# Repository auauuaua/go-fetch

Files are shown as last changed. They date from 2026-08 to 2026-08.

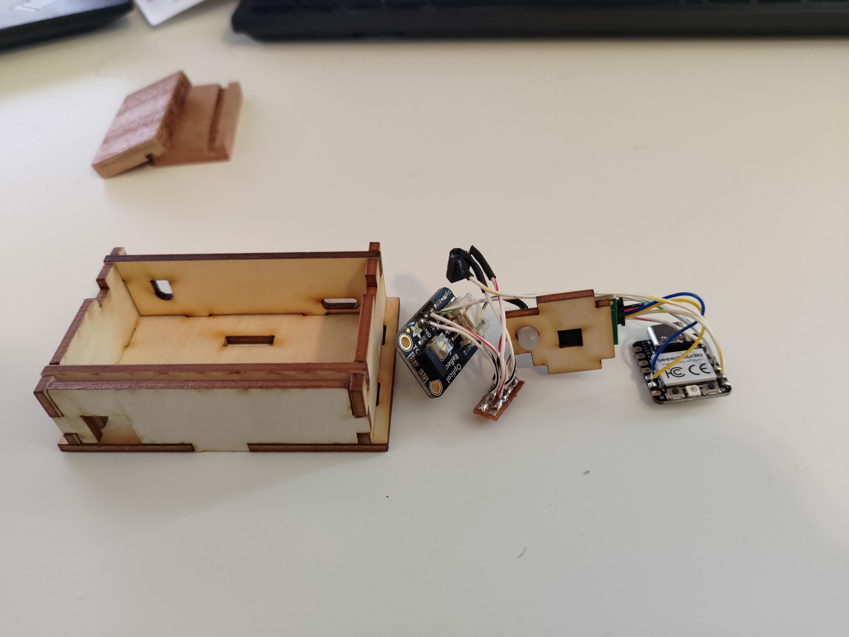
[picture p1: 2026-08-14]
go fetch Card Player Hardware/Images/P_20260420_094052_clean.jpg

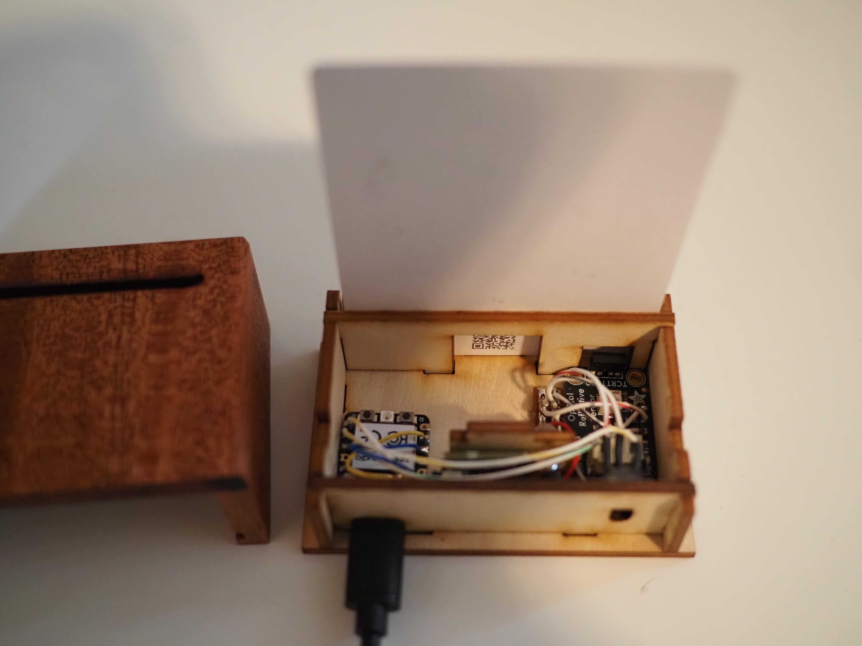
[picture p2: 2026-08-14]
go fetch Card Player Hardware/Images/P4224178_clean.JPG

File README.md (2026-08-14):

# go fetch
## De-digital horror-ify your life: hands on  physical method for accessing digital media
...and software to make viewing it suck less

## A system for easily pulling up your favorite photo albums, music playlists, etc, without touching a computer or phone.

The hardware and companion Windows software allows you to link a QR code to any file/website/etc.

The hardware accepts a standard poker sized card with the QR code on the back, so it feels more like putting in a CD than scanning a code.

The software allows easy setup of the card layout so you can get them printed, or print on cardstock yourself.

It's customizable to launch any file or link from any QR code with any program, and allows you send program specific commands to the program through a IR remote.

1. go fetch Card Player - Windows PC Editor and Launcher

2. go fetch Card Player Arduino - Arduino code for the hardware

3. go fetch Card Player Hardware - CAD Files, Schematics, etc.

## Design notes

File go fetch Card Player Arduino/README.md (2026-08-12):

# Go Fetch Card Player - Arduino

Firmware for the Go Fetch Card Player, running on a Seeed Studio XIAO RP2040. Reads QR codes from physical cards via a Tiny Code Reader (I2C) and receives IR remote signals, reporting both over Serial.

---

## Hardware

| Component | Details |
|---|---|
| Microcontroller | Seeed Studio XIAO RP2040 |
| QR Scanner | Tiny Code Reader (Useful Sensors) — I2C |
| IR Receiver | Connected to pin D2 |
| Card Detect Switch | Connected to pin D4 (active LOW, INPUT_PULLUP) |
| Illumination LED | For QR code reader lighting, connected to pin D1 |

### Wiring

| XIAO RP2040 Pin | Connected To |
|---|---|
| D6 (SDA) | Tiny Code Reader SDA |
| D7 (SCL) | Tiny Code Reader SCL |
| D4 | Card detect switch (other leg to GND) |
| D1 | QR illumination LED (with appropriate resistor) |
| D2 | IR receiver signal pin |
| 3.3V / GND | Tiny Code Reader power |

---

## Dependencies

| Library | Version | License |
|---|---|---|
| [IRremote](https://github.com/Arduino-IRremote/Arduino-IRremote) | 4.x | MIT / LGPL |
| [tiny_code_reader](https://github.com/usefulsensors/tiny_code_reader_arduino) | — | Apache 2.0 |

Install both via the Arduino Library Manager, or clone them into your `Arduino/libraries/` folder.

---

## How It Works

1. A card is inserted, closing the card detect switch (pin D4 pulled LOW).
2. The illumination LED turns on to light the QR code for the reader.
3. The Tiny Code Reader scans the card's QR code over I2C.
4. On a successful new scan, the result is printed over Serial as `QRR:<content>` and the illumination LED turns off.
5. The card can remain inserted without re-triggering; removing it prints `ejected` over Serial and resets the state.
6. IR remote signals are received independently and printed as `IR:<hex_code>`.

### Serial Output Format

| Event | Output |
|---|---|
| QR code scanned | `QRR:<decoded content>` |
| IR button pressed | `IR:<hex code>` |
| Card removed | `ejected` |

Serial baud rate: **9600**

---

## Building & Flashing

1. Open `CardPlayer_Arduino.ino` in the Arduino IDE.
2. Under **Tools > Board**, select **Seeed XIAO RP2040**.
3. Install the dependencies listed above.
4. Connect the XIAO via USB and select the correct port.
5. Click **Upload**. The board will reboot and appear as a USB drive briefly during flashing.

---

## License

This project is licensed under the [GNU General Public License v3.0](LICENSE).

Third-party libraries retain their own licenses — see the `LICENSE` file in each library's folder under `Arduino/libraries/`.

---

## Acknowledgements

- [IRremote](https://github.com/Arduino-IRremote/Arduino-IRremote) by shirriff, z3t0, ArminJo et al.
- [tiny_code_reader](https://github.com/usefulsensors/tiny_code_reader_arduino) by Useful Sensors / Pete Warden

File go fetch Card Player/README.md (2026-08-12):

# go fetch Card Player
Currently windows only software meant to be run concurrently with go fetch Card Player hardware to have hands on access to physical media. The software has two main parts:

1. Tray application - launching the exe starts a tray app that just shows in the windows system tray. This is meant to be run in the background, it connects to the hardware over usb and receives serial messages to launch user set media and software based on the QR code read by the hardware. Can set this to launch at startup through Windows. 
a system that plays media by scanning QR code cards with a custom serial card reader.

2. Editor window - accessible by launching the exe a second time or right clicking on the tray icon and clicking open editor. This is the interface to link and set up your media, players, cards, remotes, and generate card images to print.

Clicking close on the editor window just closes the editor. To fully shut down the program, right click on the tray icon and click exit. 

---

## Requirements

- Windows 10/11
- [.NET 8.0 Desktop Runtime](https://dotnet.microsoft.com/download/dotnet/8.0) (or SDK to build)

## Build & Publish

```powershell
cd CardPlayer
dotnet restore
dotnet run                  # run from source

# Publish as a single self-contained exe
dotnet publish -c Release -r win-x64 --self-contained true -p:PublishSingleFile=true
# Output: bin\Release\net8.0-windows\win-x64\publish\
```

---

## Data Directory

All configuration files are read from and written to:

```
%LOCALAPPDATA%\go fetch\go fetch Card Player
```

On first run the app creates this folder and any missing files with default content.

| File | Description |
|---|---|
| `Players.json` | Media type definitions — programs, functions, remote mappings |
| `Cards.csv` | Media library — QR codes, media paths, art, program type assignments, and per-card layout settings |
| `RemoteProfiles.json` | Remote profiles used for button mapping |
| `Hardware.json` | Serial device VID/PID and debug logging flag |
| `card_settings.json` | Saved settings for the card generator |
| `scan_settings.json` | Saved settings for the media scanner |
| `cardplayer_debug.log` | Debug log (only written when `DebugLogging` is enabled) |

---

## Cards.csv Column Reference

Columns are matched by name in the header row — order does not matter and unknown
columns are ignored. Only rows with a value in the `Path` column are imported.

| Column | Description |
|---|---|
| `Type_Digit` | Numeric string matching a player type tab (e.g. `1`, `2`) |
| `Title` | Label shown on the card and overlaid as text (supports multiple lines) |
| `QR_Code` | The string encoded in the QR code (max 32 alphanumeric chars, auto-trimmed) |
| `Path` | Full path to the media file or folder. **Required** — rows without this are skipped on import |
| `Art_Path` | Full path to the front card art image |
| `Art_Fit` | How the front art is scaled: `fill`, `fit`, `square fill`, or `square fit` |
| `Art_Back_Path` | Full path to the back card art image. Always rendered as **fit** (letterboxed). Drawn over the background colour, under the QR code |
| `State` | `new`, `skip`, or `generated` — tracks card generation status |
| `Text_Side` | `front` or `back` — which card face receives the title overlay |
| `Text_Font` | Font family name (blank = system default) |
| `Text_Style` | `Normal`, `Bold`, `Italic`, or `Bold Italic` |
| `Text_Size` | Font size in points |
| `Text_Color` | Hex color for the title overlay (e.g. `#000000`) |
| `Front_Bg_Color` | Hex background color for the front card (e.g. `#FFFFFF`) |
| `Back_Bg_Color` | Hex background color for the back card |

---

## Main Window Bar

### Save/discard buttons
Changes made within the editor are for the most part not saved until you click the Save All button in the top bar, or press "Ctrl+s". 
A blue dot will show next to the discard changes button when there exists an unsaved change, as well as a blue dot next to the top level tab of wherever unsaved changes are. 
Clicking the Discard Changes button at the top will just reload the data from disk, so any changes will be undone since last save.
there are a few exceptions to this, changes to scan settings and print profile settings are saved automatically.

### Remote Passthrough
Once you have a remote setup and a player setup to map the remote, you can enable remote passthrough at the top left of the window bar.
Enabling this will execute any received remote commands as mapped by the player type selected in the drop down even if there is no card currently detected by the hardware.
(If there is a card detected by the hardware, remote passthrough is overridden.)

## Tabs

In order you would set up for the first time

### Hardware
Configure the serial device VID/PID. Changes take effect after restarting the app.

### Players
Defines types of media and assigns one program to launch any media assigned to that type — (photos, music, video game, etc.). Each type has:

- **Program** — the executable to launch with the media path as argument
- **Launch options** — extra CLI arguments (e.g. `--new-window`, `--fullscreen`)
- **Send after launch** — a function to call after the program opens (with optional delay)
- **Dispatch method** — how Remote commands are sent (`sendkeys`, `vk`, or `tcp`)
- **Functions** — named key actions assigned to remote buttons (e.g. Play/Pause → `MEDIA_PLAY_PAUSE`)
- **Remote mapping** — maps each physical remote button to a function (must set up remote profile before you map anything)
- **Shift keys** — defines buttons to activate a secondary remote mapping layer

### Cards
Manages card/media setup. Each row links a QR code string to a media file/folder and a program type.
Scan and auto-populate, enter manually, or load from a CSV. You can also drag a file or folder from
Windows Explorer directly onto a grid cell to fill its path.
You also set the layout and design of the physical cars to be created here; titles, art, colors, font, etc. 
Scan for or set front and back art paths to use images when generating card image files. Titles support
multiple lines (press Enter in the title field).
Below each card preview is the "go fetch" button that will allow you to test what will happen when that card is inserted in the hardware.

### Remote Setup
Defines remote control profiles — the physical buttons and their IR codes. Multiple profiles are supported but only the selected one is active. Changing the remote profile may require adjusting individual mappings in the Players tab.

### Print Generator
Generates card images (fronts and/or backs) from the media library as either individual card PNGs or a grid to print as a sheet. Can generate just the QR as an image for custom setup elsewhere, or a grid of QR codes to print on stickers. Supports custom card size, margins, art fit modes (including square fit/fill), front and back art, title text overlay, and rounded outline cutting guides.

---

## Debug Logging

To enable verbose logging, manually edit `Hardware.json` and set:

```json
{
  "DebugLogging": true
}
```

Logs are written to `cardplayer_debug.log` in the data directory (`%LOCALAPPDATA%\go fetch Card Player`). Disable by setting back to `false`. The app reads this at startup.

---

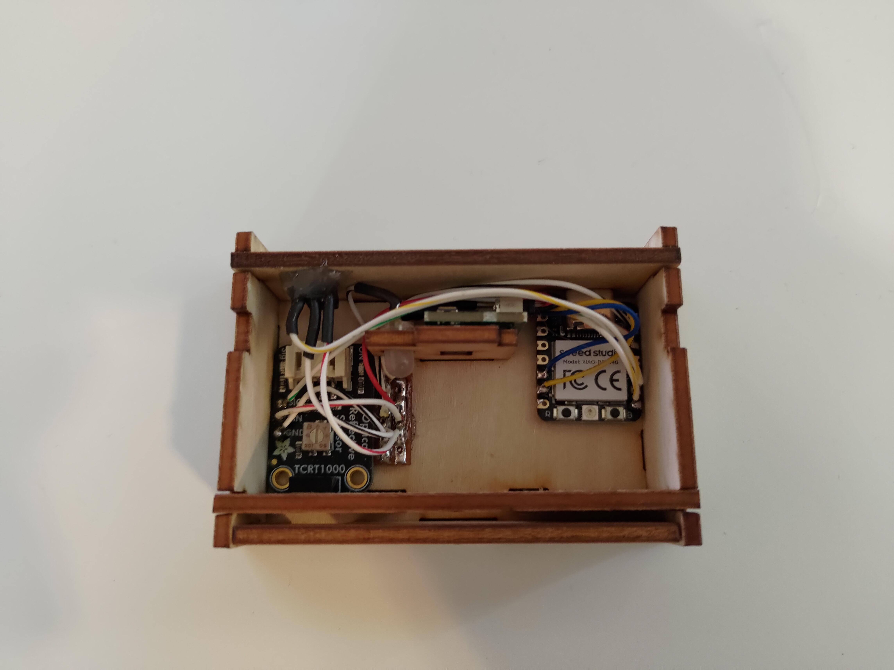
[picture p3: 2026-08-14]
go fetch Card Player Hardware/Images/P_20260420_095108_clean.jpg

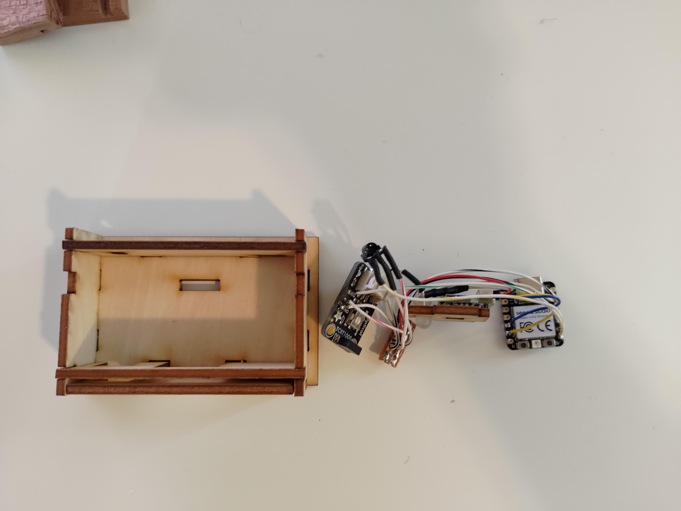
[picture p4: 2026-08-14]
go fetch Card Player Hardware/Images/P_20260420_094048_clean.jpg

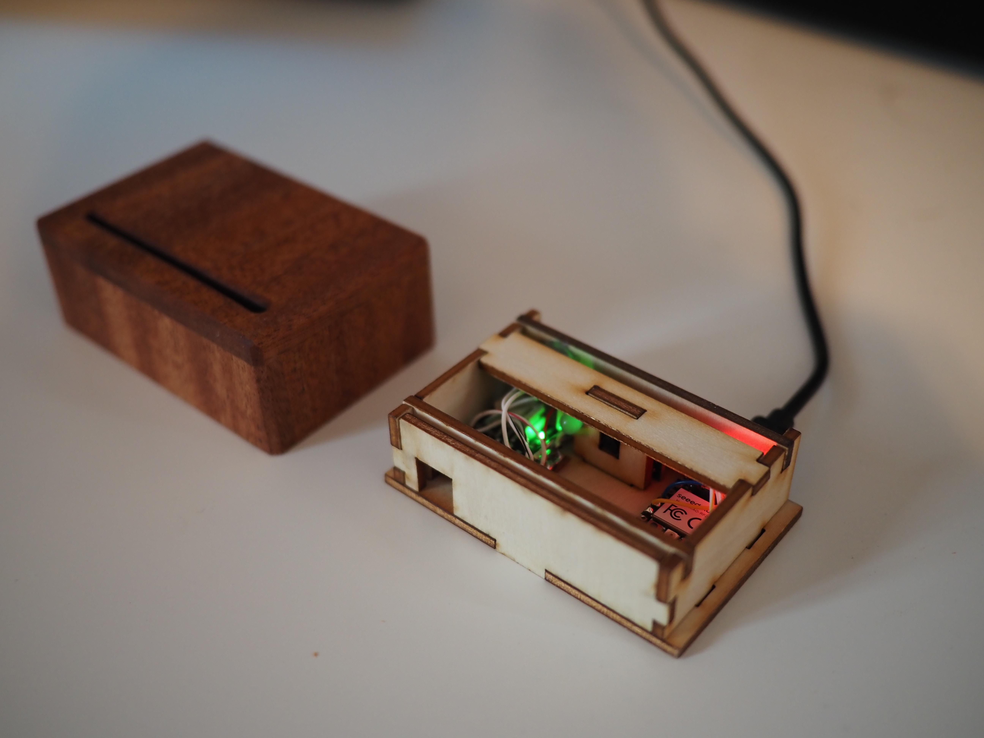
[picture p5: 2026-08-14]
go fetch Card Player Hardware/Images/P4224163_clean.JPG

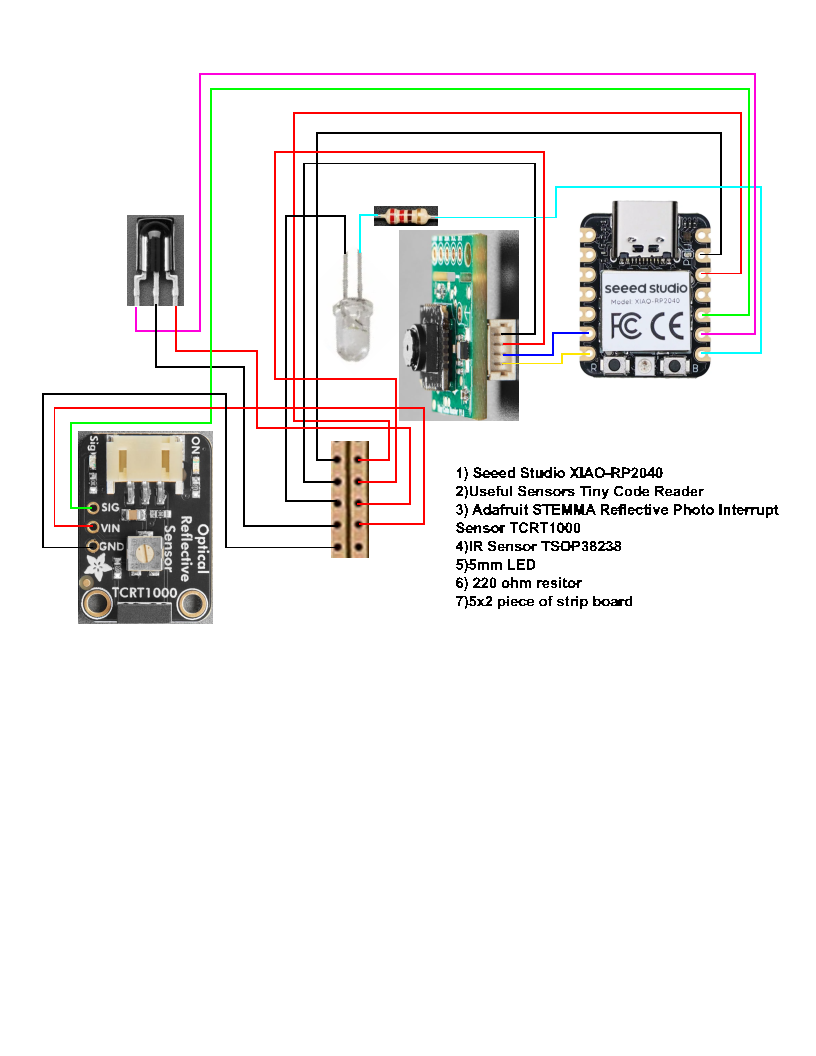
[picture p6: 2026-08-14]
go fetch Card Player Hardware/electronics schematic.png

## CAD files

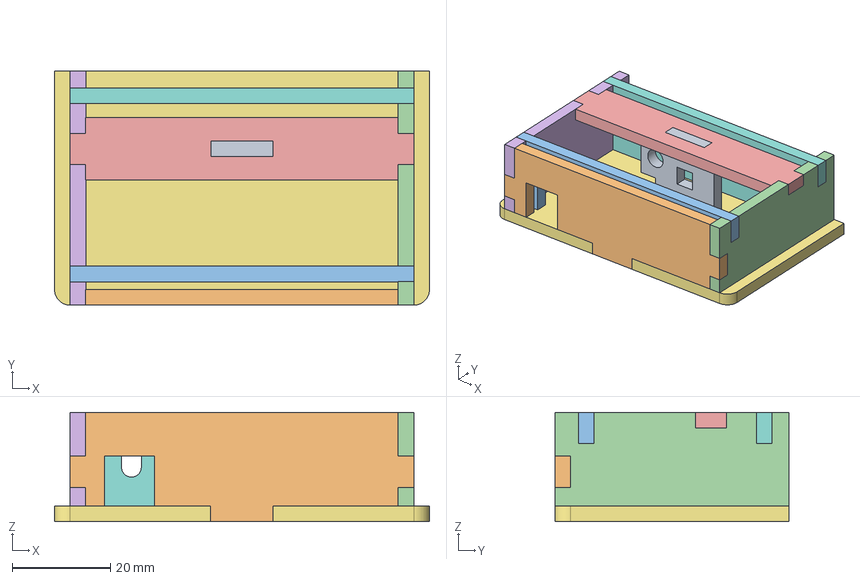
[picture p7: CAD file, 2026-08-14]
go fetch Card Player Hardware/gofetchCardPlayer_enclosure.FCStd
76.2 x 47.6 x 22.2 mm
inner Camera bar
inner card front
inner card back
inner left
inner camera bar top
inner right
inner bottom
inner Back XAIO

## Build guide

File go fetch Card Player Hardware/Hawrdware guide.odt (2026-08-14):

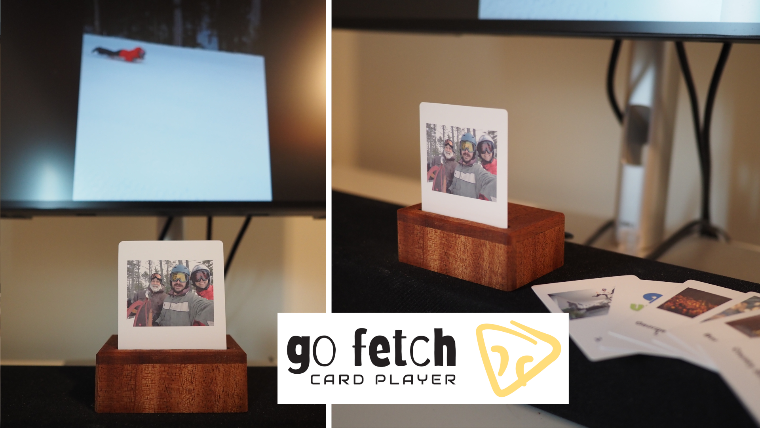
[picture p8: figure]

Hardware Guide:

1. Inner Enclosure: The hardware is designed around a laser cut inner enclosure that holds all electronics and the inserted card. The inner enclosure is 1/8” or 3mm thick.

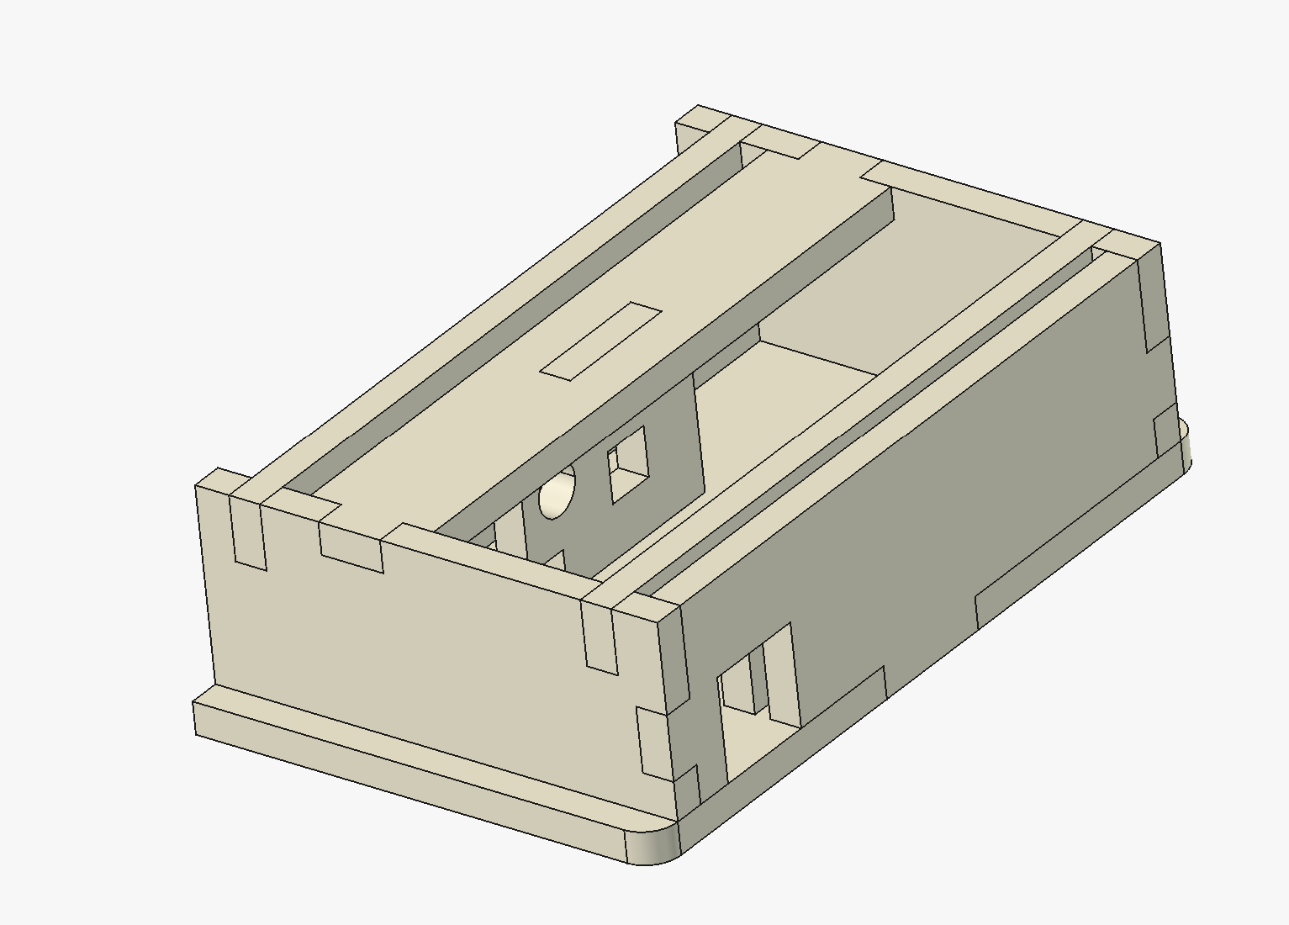
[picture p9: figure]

2. Outer Enclosure: 4 sided outer enclosure (¼” thick), inner enclosure slides into it from the back friction fit.

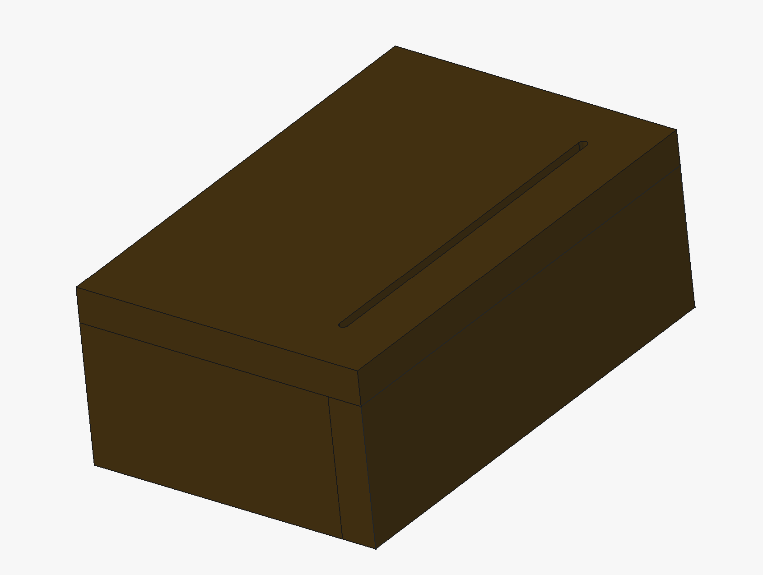
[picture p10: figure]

3. Electronics: Note will need STEMMA/Qwiic connector cable for tiny code reader. Top optional direct solder part of the board needs to be clipped off for it to fit in the enclosure. Images helpful for assembly in images folder

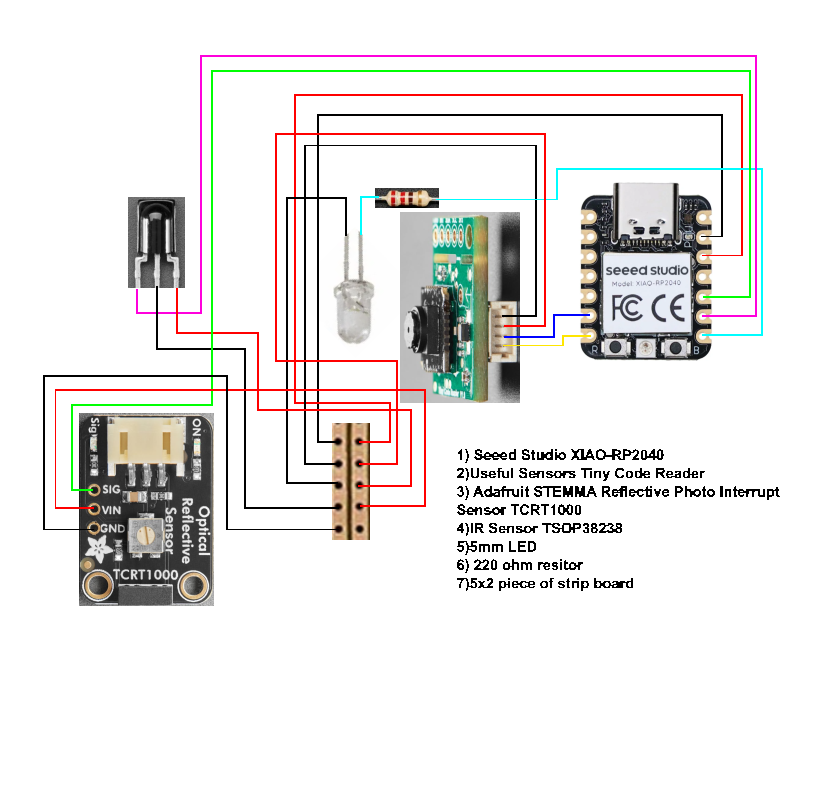
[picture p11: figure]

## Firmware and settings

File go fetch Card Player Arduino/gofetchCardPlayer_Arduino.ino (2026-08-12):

/*
 * QR Code + IR Remote Reader
 *
 * Reads QR codes via a Tiny Code Reader (I2C) and IR remote signals.
 * Outputs decoded data over Serial in the format:
 *   QRR:<content>   — on a new QR scan
 *   IR:<hex_code>   — on an IR button press
 *   ejected         — when the card/trigger is removed
 *
 * Hardware:
 *   - Tiny Code Reader on SDA=6, SCL=7 (I2C)
 *   - Card detect switch on pin 4 (INPUT_PULLUP, active LOW)
 *   - QR Illumination LED on pin 1
 *   - IR receiver on pin 2
 *
 * Dependencies: IRremote, tiny_code_reader
 * 
 * Note if using second I2C connection like the stemma connector on Adafruit QTPY rp2040, 
 * you will need to change all instances of Wire to Wire1 (except the #include <Wire.h> lines)in this file and in tiny_code_reader.h
 * and of course pin numbers as needed
 */

#include <Wire.h>
#include <IRremote.hpp>
#include "tiny_code_reader.h"

// --- Pin assignments ---
const int PIN_CARD_DETECT = 4;
const int PIN_ILLUM_LED  = 1;
const int PIN_IR_RECEIVER = 2;

// --- Timing ---
const int32_t  SAMPLE_DELAY_MS  = 200;  // Sensor updates at ~5 FPS
const uint32_t DEBOUNCE_DELAY_MS = 200; // Minimum ms between repeated IR signals

// --- State ---
char     lastScannedCode[128] = "";
bool     cardInserted         = false;
uint32_t lastIRCode           = 0;
uint32_t lastIRTime           = 0;

void setup() {
  Wire.setSDA(6);
  Wire.setSCL(7);
  Wire.begin();
  Serial.begin(9600);

  pinMode(PIN_CARD_DETECT, INPUT_PULLUP);
  pinMode(PIN_ILLUM_LED,  OUTPUT);
  IrReceiver.begin(PIN_IR_RECEIVER);
}

void loop() {
  tiny_code_reader_results_t results = {};

  if (!tiny_code_reader_read(&results)) {
    Serial.println("No person sensor results found on the i2c bus");
    delay(SAMPLE_DELAY_MS);
    return;
  }

  // --- Card detect ---
  bool cardPresent = (digitalRead(PIN_CARD_DETECT) == LOW);

  if (cardPresent) {
      if (!cardInserted) {
          digitalWrite(PIN_ILLUM_LED, HIGH);
  
          if (results.content_length > 0) {
              char* scanned = (char*)results.content_bytes;
  
              if (strcmp(scanned, lastScannedCode) != 0) {
                  strncpy(lastScannedCode, scanned, sizeof(lastScannedCode) - 1);
                  lastScannedCode[sizeof(lastScannedCode) - 1] = '\0';
  
                  Serial.print("QRR:");
                  Serial.println(lastScannedCode);
  
                  digitalWrite(PIN_ILLUM_LED, LOW);
                  cardInserted = true;
              }
          }
      }
  } else {
    if (cardInserted) {
      Serial.println("ejected");
    }
    cardInserted        = false;
    lastScannedCode[0]  = '\0';
    digitalWrite(PIN_ILLUM_LED, LOW);
  }

  // --- IR receiver ---
  if (IrReceiver.decode()) {
    if (IrReceiver.decodedIRData.protocol != UNKNOWN) {
      uint32_t now = millis();

      if (IrReceiver.decodedIRData.flags & IRDATA_FLAGS_IS_REPEAT) {
        if (now - lastIRTime >= DEBOUNCE_DELAY_MS) {
          Serial.print("IR:");
          Serial.println(lastIRCode, HEX);
          lastIRTime = now;
        }
      } else {
        lastIRCode = IrReceiver.decodedIRData.decodedRawData;
        Serial.print("IR:");
        Serial.println(lastIRCode, HEX);
        lastIRTime = now;
      }
    }
    IrReceiver.resume();
  }

  delay(SAMPLE_DELAY_MS);
}
